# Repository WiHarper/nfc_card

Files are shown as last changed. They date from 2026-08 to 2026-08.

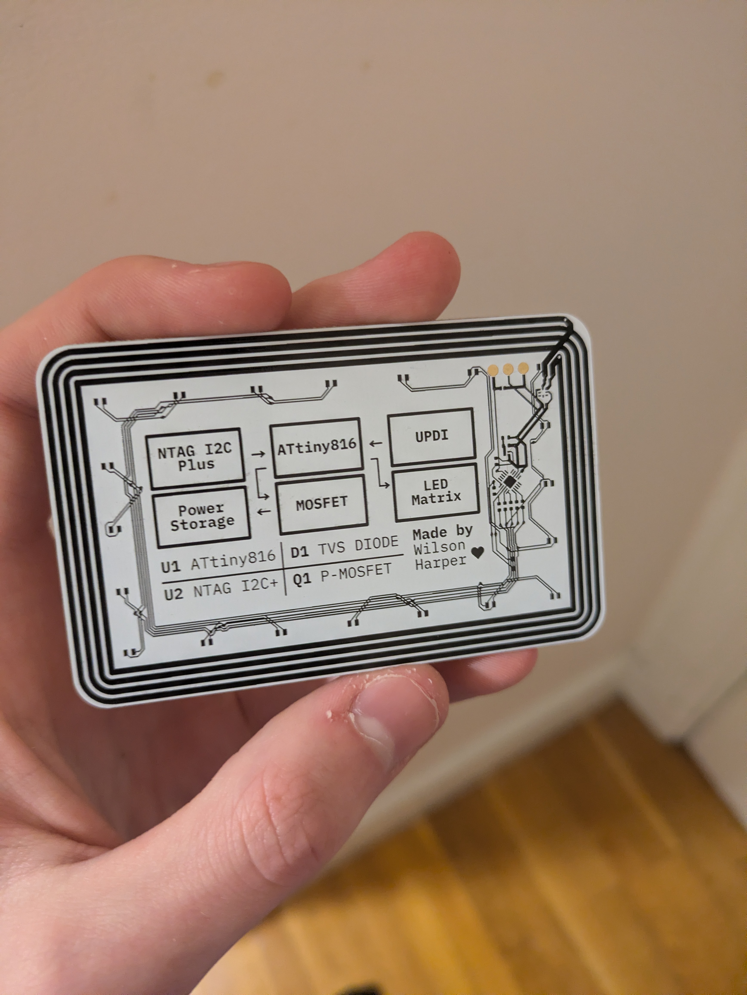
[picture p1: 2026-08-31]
gallery/in_hand_back.jpg

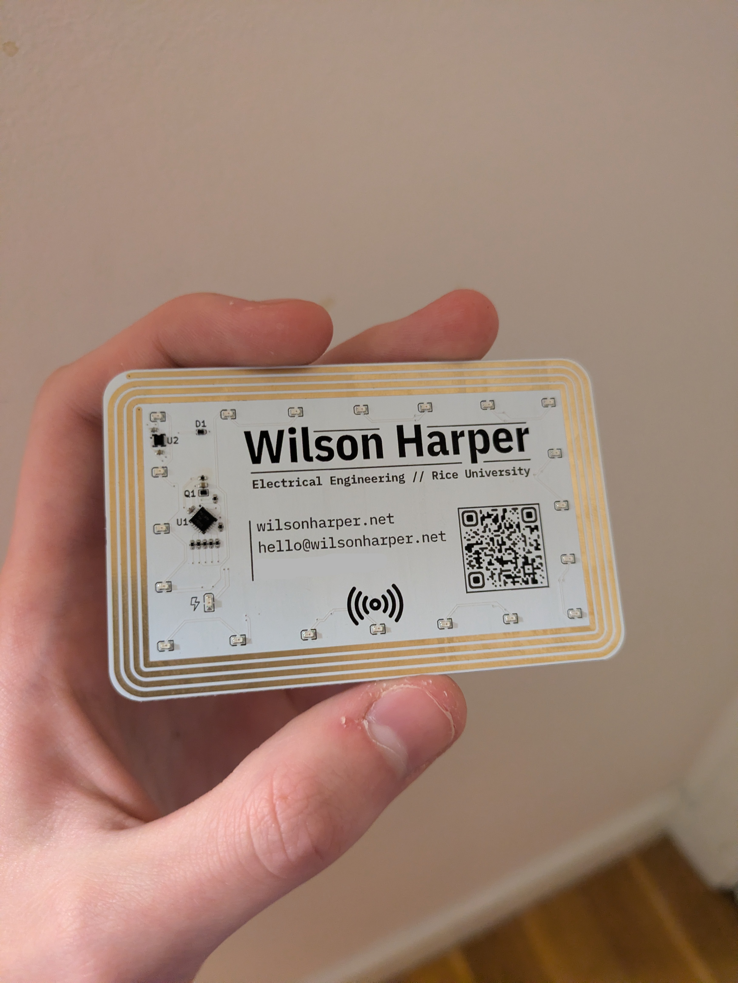
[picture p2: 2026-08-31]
gallery/in_hand.jpg

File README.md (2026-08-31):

# NFC Energy-Harvesting PCB Business Card with an MCU



Like most business cards, this one doesn’t have a battery. When it’s tapped against a phone, though, 21 LEDs start an animation, powered just by NFC.

**Find more information at [wlsn.ee/nfc](https://wlsn.ee/nfc).**

## Details

* MCU: ATtiny816 
* NFC Chip: NXP NTAG I2C Plus
* Antenna: Custom rectangular coil tuned to ~2.75 µH
* Display: 21 Charlieplexed LEDs
* Dimensions: Payment card form factor

## Repository Layout

* `hardware/` - KiCad 9.0 schematic files/PCB layout files and 3D models
* `software/` - firmware and KiPython script
* `gallery/` - photos/video of card

## Programming

The ATtiny is flashed over UPDI; its clock speed should be set to 1 MHz. The NFC chip is formatted and written using [NXP Tagwriter](https://play.google.com/store/apps/details?id=com.nxp.nfc.tagwriter&hl=en_US). Energy harvesting is enabled by default, and it is easy to add vCard records or a website link.

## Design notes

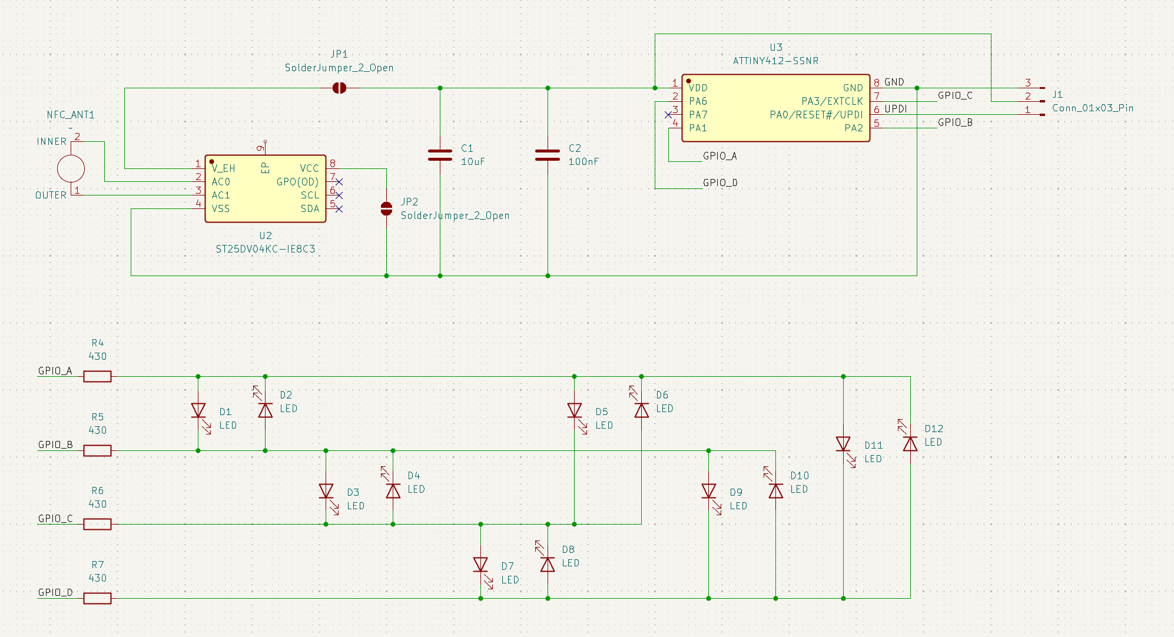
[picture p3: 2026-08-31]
gallery/sch1.png

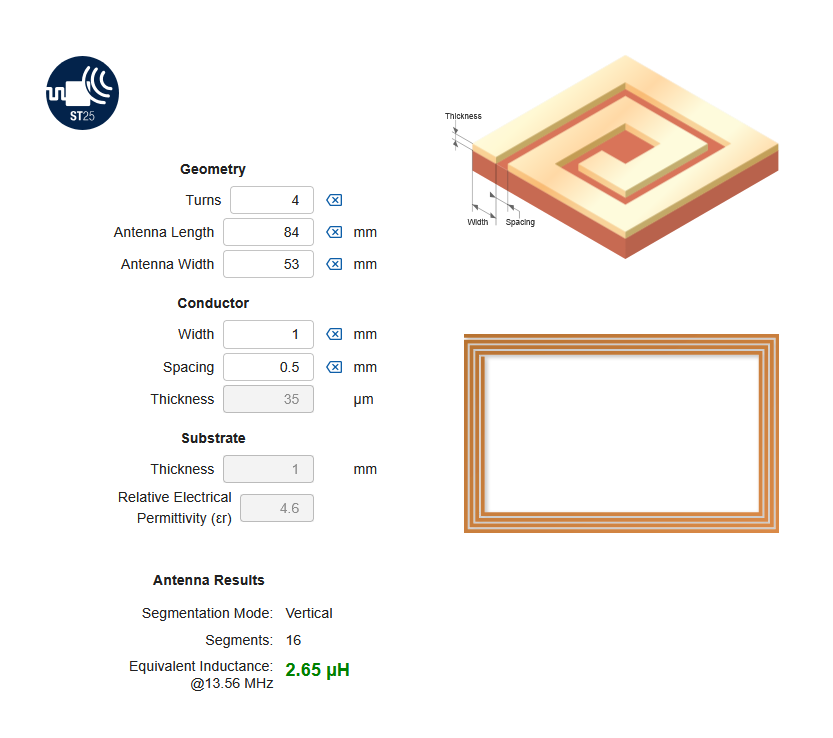
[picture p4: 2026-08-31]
gallery/st_calc.png

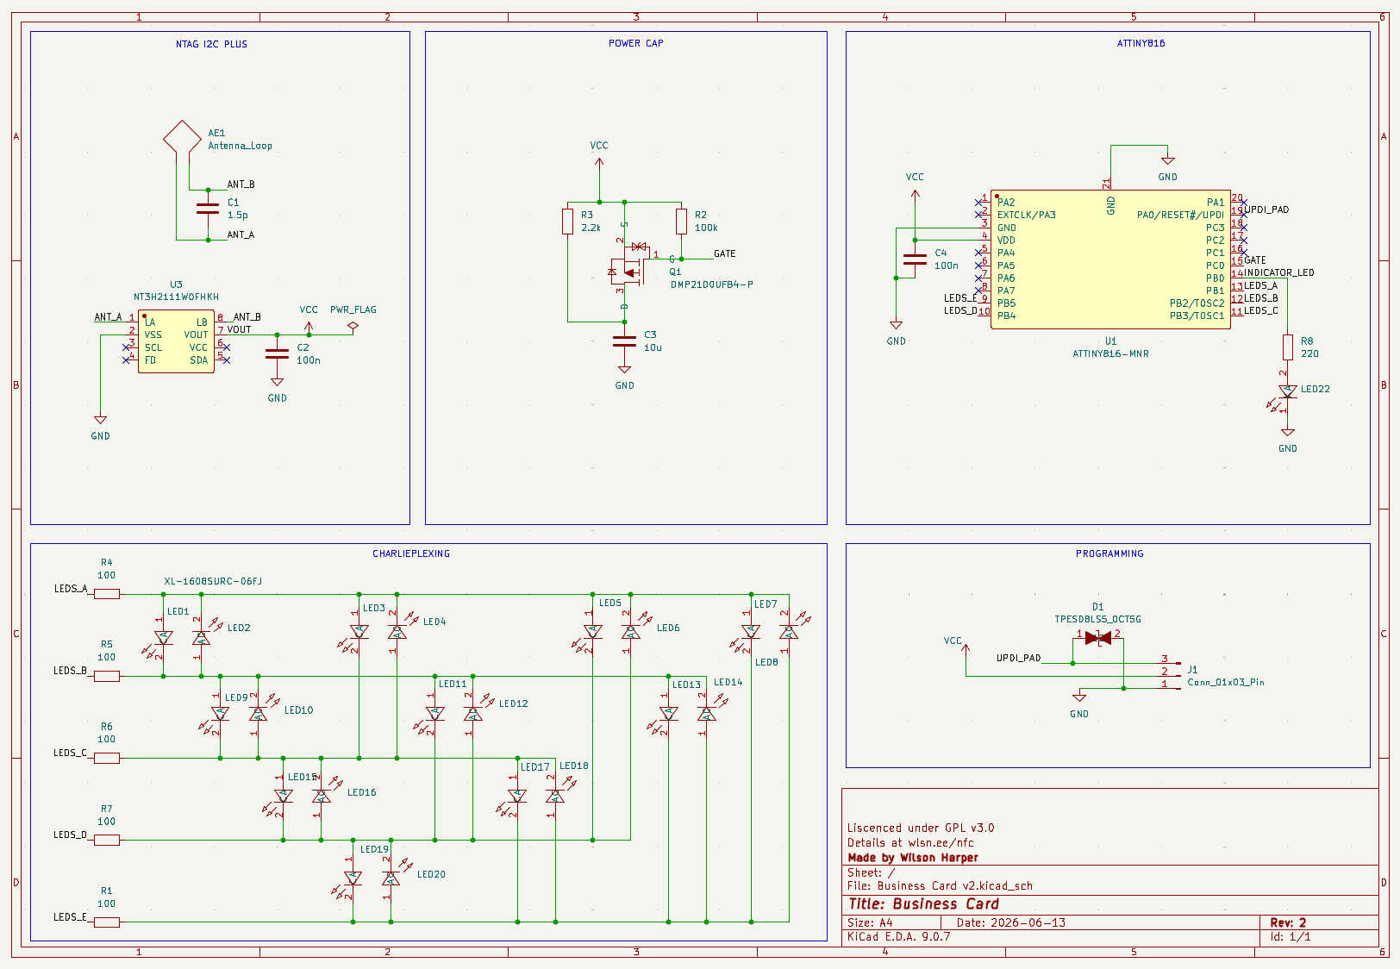
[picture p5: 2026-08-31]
gallery/new_sch.png

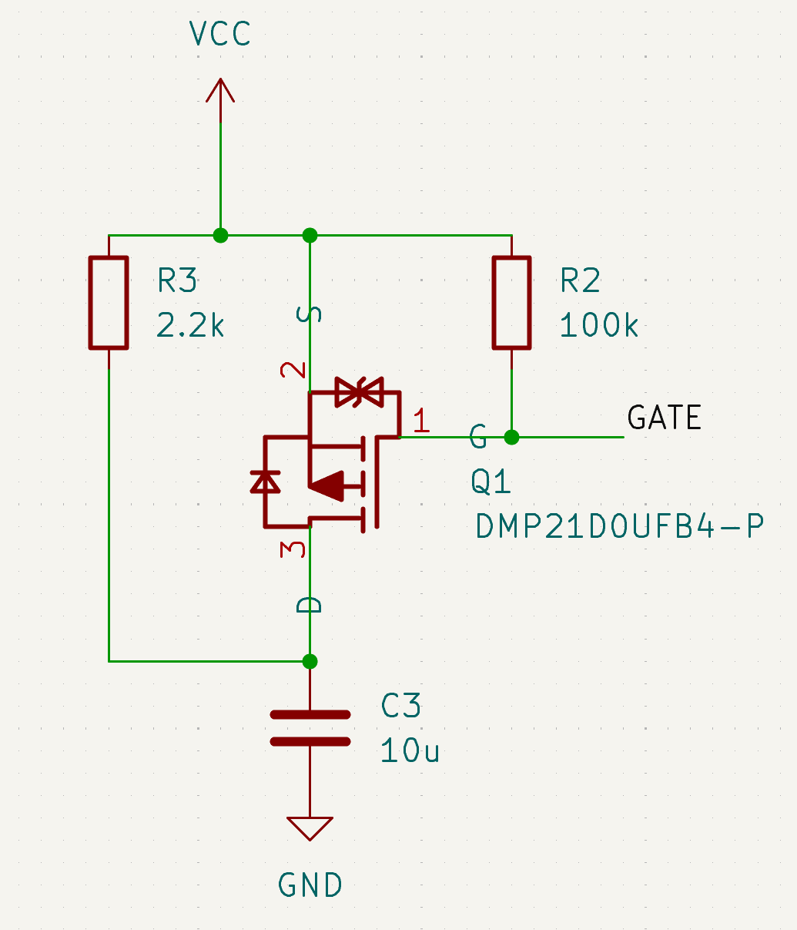
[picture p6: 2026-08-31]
gallery/capacitor.png

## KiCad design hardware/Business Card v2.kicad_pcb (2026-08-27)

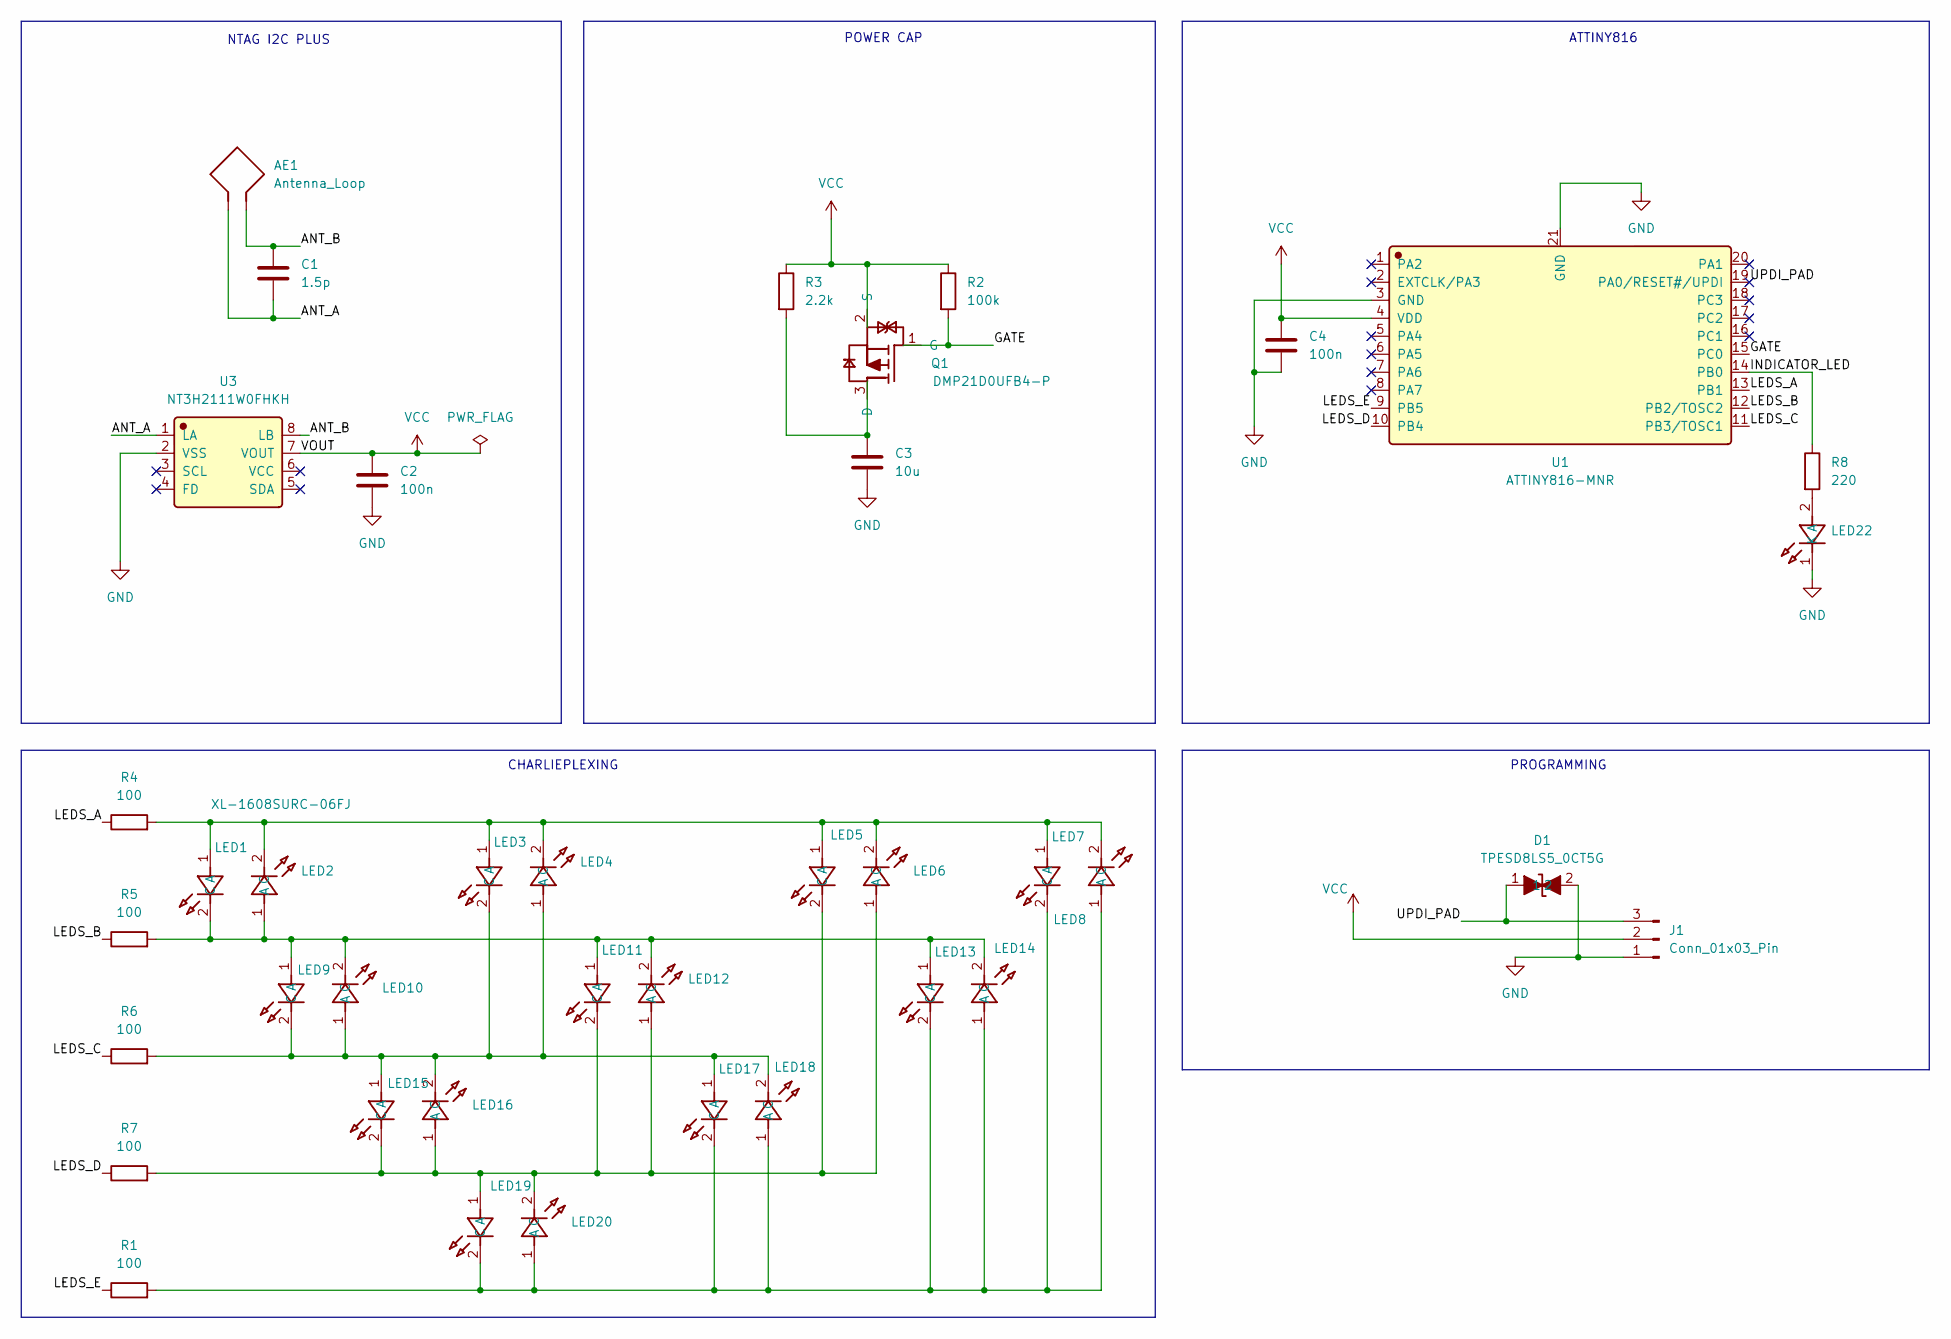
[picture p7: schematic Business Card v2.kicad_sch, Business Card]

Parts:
AE1: Antenna_Loop; Antenna V3
C1: 1.5p; C_0402_1005Metric; LCSC C1639
C2, C4: 100n; C_0402_1005Metric; LCSC C1525
C3: 10u; C_0402_1005Metric; LCSC C15525
D1: TPESD8LS5_0CT5G; TPESD8L3_3CT5G; Manufacturer Part TPESD8LS5.0CT5G; LCSC C2827551
J1: Conn_01x03_Pin; Offset UPDI
LED1, LED2, LED3, LED4, LED5, LED6, LED7, LED8, LED9, LED10, LED11, LED12, LED13, LED14, LED15, LED16, LED17, LED18, LED19, LED20: XL-1608SURC-06FJ; Manufacturer Part XL-1608SURC-06FJ; LCSC C7371900
LED22: XL-1608UYC-06FJ; Manufacturer Part XL-1608UYC-06FJ; LCSC C7371901
Q1: DMP21D0UFB4-P; Manufacturer Part DMP21D0UFB4-P; LCSC C2905648
R1, R5, R6, R7: 100; R_0402_1005Metric; LCSC C25076
R2: 100k; R_0402_1005Metric; LCSC C25741
R3: 2.2k; R_0402_1005Metric; LCSC C25879
R4: 100; R_0402_1005Metric
R8: 220; R_0402_1005Metric; LCSC C25091
U1: ATTINY816-MNR; Manufacturer Part ATTINY816-MNR; LCSC C2052778
U3: NT3H2111W0FHKH; Manufacturer Part NT3H2111W0FHKH; LCSC C710403

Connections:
/ANT_A: AE1.1, C1.2, U3.1 (LA)
/ANT_B: AE1.2, C1.1, U3.8 (LB)
/GATE: Q1.1 (G), R2.2, U1.15 (PC0)
/INDICATOR_LED: R8.1, U1.14 (PB0)
/LEDS_A: R4.1, U1.13 (PB1)
/LEDS_B: R5.1, U1.12 (PB2/TOSC2)
/LEDS_C: R6.1, U1.11 (PB3/TOSC1)
/LEDS_D: R7.1, U1.10 (PB4)
/LEDS_E: R1.1, U1.9 (PB5)
/UPDI_PAD: D1.1, J1.3, U1.19 (PA0/RESET#/UPDI)
GND: C2.2, C3.2, C4.2, D1.2, J1.1, LED22.1 (K), U1.3 (GND), U1.21 (GND), U3.2 (VSS)
unnamed: LED1.1 (A), LED2.2 (C), LED3.1 (A), LED4.2 (C), LED5.1 (A), LED6.2 (C), LED7.2 (C), LED8.1 (A), R4.2
unnamed: LED1.2 (C), LED2.1 (A), LED9.1 (A), LED10.2 (C), LED11.1 (A), LED12.2 (C), LED13.1 (A), LED14.2 (C), R5.2
unnamed: LED3.2 (C), LED4.1 (A), LED9.2 (C), LED10.1 (A), LED15.1 (A), LED16.2 (C), LED17.1 (A), LED18.2 (C), R6.2
unnamed: LED5.2 (C), LED6.1 (A), LED11.2 (C), LED12.1 (A), LED15.2 (C), LED16.1 (A), LED19.1 (A), LED20.2 (C), R7.2
unnamed: LED7.1 (A), LED8.2 (C), LED13.2 (C), LED14.1 (A), LED17.2 (C), LED18.1 (A), LED19.2 (C), LED20.1 (A), R1.2
unnamed: LED22.2 (A), R8.2
unnamed: C3.1, Q1.3 (D), R3.2
VCC: C2.1, C4.1, J1.2, Q1.2 (S), R2.1, R3.1, U1.4 (VDD), U3.7 (VOUT)

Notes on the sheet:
NTAG I2C PLUS
POWER CAP
ATTINY816
PROGRAMMING
CHARLIEPLEXING

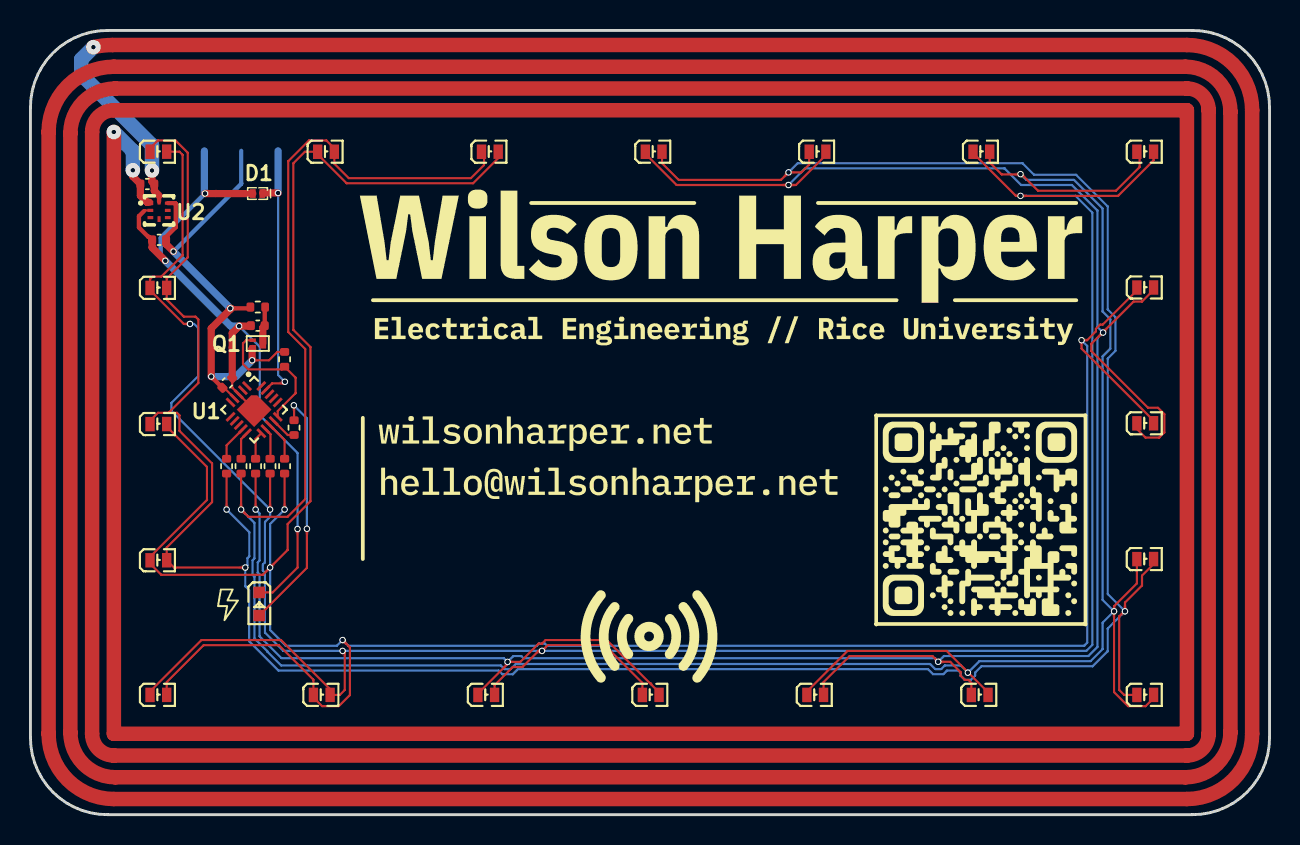
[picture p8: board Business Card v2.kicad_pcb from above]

Board: 2 copper layers, 85.4 x 54.1 mm, 39 parts (1 on the bottom side), 19 nets.

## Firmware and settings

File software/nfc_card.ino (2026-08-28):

const int powerBypassPin = PIN_PC0;
const int powerLedPin = PIN_PB0;


struct LedMap {
  uint8_t anodeIdx;
  uint8_t cathodeIdx;
};


const LedMap leds[20] = {
  {1, 4}, {4, 1}, {0, 4}, {4, 0}, {0, 1}, {1, 0}, {1, 2}, {2, 1},
  {2, 3}, {3, 2}, {3, 4}, {4, 3}, {0, 2}, {2, 0}, {1, 3}, {3, 1},
  {2, 4}, {4, 2}, {0, 3}, {3, 0}  
};


struct LedMasks {
  uint8_t dir_mask;
  uint8_t out_mask;
};
LedMasks ledMasks[20];


// Marquee tracking variables
uint8_t circleHead = 0;
uint16_t frameCounter = 0;
unsigned long setupEndTime = 0;


float powerBrightness = 127.0f;
float breatheStep = -0.25f;


#define MORSE_UNIT 170


struct MorseElement {
  bool pinState;
  uint8_t units;
};

const MorseElement morseSequence[] = {
  {true, 1}, {false, 1}, {true, 3}, {false, 1}, {true, 3}, {false, 3},
  {true, 1}, {false, 1}, {true, 1}, {false, 3},
  {true, 1}, {false, 1}, {true, 3}, {false, 1}, {true, 1}, {false, 1}, {true, 1}, {false, 3},
  {true, 1}, {false, 1}, {true, 1}, {false, 1}, {true, 1}, {false, 3},
  {true, 3}, {false, 1}, {true, 3}, {false, 1}, {true, 3}, {false, 3},
  {true, 3}, {false, 1}, {true, 1}, {false, 3},
  {true, 1}, {false, 1}, {true, 1}, {false, 1}, {true, 1}, {false, 1}, {true, 1}, {false, 3},
  {true, 1}, {false, 1}, {true, 3}, {false, 3},
  {true, 1}, {false, 1}, {true, 3}, {false, 1}, {true, 1}, {false, 3},
  {true, 1}, {false, 1}, {true, 3}, {false, 1}, {true, 3}, {false, 1}, {true, 1}, {false, 3},
  {true, 1}, {false, 3},
  {true, 1}, {false, 1}, {true, 3}, {false, 1}, {true, 1}, {false, 3},
  {true, 1}, {false, 1}, {true, 3}, {false, 1}, {true, 1}, {false, 1}, {true, 3}, {false, 1}, {true, 1}, {false, 1}, {true, 3}, {false, 3},
  {true, 3}, {false, 1}, {true, 1}, {false, 3},
  {true, 1}, {false, 3},
  {true, 3}, {false, 7}
};


const uint8_t morseLength = sizeof(morseSequence) / sizeof(morseSequence[0]);
uint8_t morseIndex = 0;
unsigned long lastMorseTransition = 0;
bool morseEngineInitialized = false;


void setup() {
  // in-rush prevention
  delay(300);


  // enable bypass MOSFET
  pinMode(powerBypassPin, OUTPUT);
  digitalWrite(powerBypassPin, LOW);


  // enable power LED
  pinMode(powerLedPin, OUTPUT);
  analogWrite(powerLedPin, 0);
 
  // pre-calculate hardware bitmasks
  for (int i = 0; i < 20; i++) {
    uint8_t aMask = (1 << (leds[i].anodeIdx + 1));
    uint8_t cMask = (1 << (leds[i].cathodeIdx + 1));
    ledMasks[i].dir_mask = aMask | cMask;          
    ledMasks[i].out_mask = aMask;                  
  }


  PORTB.DIRCLR = 0x3E;


  uint32_t startupStart = millis();


  while (millis() - startupStart < 300) {
    uint32_t elapsed = millis() - startupStart;
    uint16_t blankingDelay = (300 - elapsed) * 25;
   
    renderMatrixCometTail(0, 0);
   
    if (blankingDelay > 0) {
      delayMicroseconds(blankingDelay);
    }
   
    uint8_t powerFade = (elapsed * 127) / 300;
    analogWrite(powerLedPin, powerFade);
  }


  circleHead = 0;
  frameCounter = 0;
  setupEndTime = millis();
}


void loop() {
  renderMatrixCometTail(circleHead, frameCounter);


  frameCounter++;
  if (frameCounter >= 67) {
    circleHead = (circleHead + 1) % 20;
    frameCounter = 0;
  }


  unsigned long currentMillis = millis();


  if (currentMillis - setupEndTime < 10000) {
   
    // power LED breathing
    powerBrightness += breatheStep;
    if (powerBrightness >= 127.0f) {
      powerBrightness = 127.0f;
      breatheStep = -breatheStep;
    } else if (powerBrightness <= 0.0f) {
      powerBrightness = 0.0f;
      breatheStep = -breatheStep;
    }
    analogWrite(powerLedPin, (int)powerBrightness);


  } else {
   
    // easter egg
    if (!morseEngineInitialized) {
      lastMorseTransition = currentMillis;
      morseIndex = 0;
      analogWrite(powerLedPin, morseSequence[morseIndex].pinState ? 127 : 0);
      morseEngineInitialized = true;
    }


    unsigned long requiredDuration = (unsigned long)morseSequence[morseIndex].units * MORSE_UNIT;


    if (currentMillis - lastMorseTransition >= requiredDuration) {
      morseIndex = (morseIndex + 1) % morseLength;
      lastMorseTransition = currentMillis;
     
      analogWrite(powerLedPin, morseSequence[morseIndex].pinState ? 127 : 0);
    }
  }
}


void renderMatrixCometTail(uint8_t headIdx, uint16_t fCount) {
  for (uint8_t i = 0; i < 20; i++) {
    uint8_t dist = (headIdx - i + 20) % 20;


    if (dist >= 17) {
      continue;
    }


    if (dist == 16) {
      if (fCount >= 50) continue;
      else if (fCount >= 34 && (fCount & 3) != 0) continue;
      else if (fCount >= 17 && (fCount & 1) != 0) continue;
    }


    uint8_t dm = ledMasks[i].dir_mask;
    uint8_t om = ledMasks[i].out_mask;


    PORTB.OUTCLR = dm;
    PORTB.OUTSET = om;
    PORTB.DIRSET = dm;


    switch (dist) {
      case 0:
      case 1:
      case 2:  __builtin_avr_delay_cycles(100); break;
      case 3:  __builtin_avr_delay_cycles(70);  break;
      case 4:  __builtin_avr_delay_cycles(48);  break;
      case 5:  __builtin_avr_delay_cycles(32);  break;
      case 6:  __builtin_avr_delay_cycles(22);  break;
      case 7:  __builtin_avr_delay_cycles(15);  break;
      case 8:  __builtin_avr_delay_cycles(10);  break;
      case 9:  __builtin_avr_delay_cycles(7);   break;
      case 10: __builtin_avr_delay_cycles(5);   break;
      case 11: __builtin_avr_delay_cycles(4);   break;
      case 12: __builtin_avr_delay_cycles(3);   break;
      case 13: __builtin_avr_delay_cycles(2);   break;
      case 14: __builtin_avr_delay_cycles(1);   break;
      case 15: __builtin_avr_delay_cycles(1);   break;
      case 16: __builtin_avr_delay_cycles(1);   break;
    }


    PORTB.DIRCLR = dm;
  }
}

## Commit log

2026-08-22 Initial upload
    [Business Card v2.kicad_pcb, Business Card v2.kicad_sch]
2026-08-31 Update details
    [Business Card v2.kicad_pcb, Business Card v2.kicad_sch]

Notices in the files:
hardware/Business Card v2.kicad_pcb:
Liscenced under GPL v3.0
